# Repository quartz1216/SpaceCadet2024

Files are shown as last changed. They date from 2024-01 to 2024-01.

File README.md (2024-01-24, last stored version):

# SpaceCadet2024
## Schematic
schematic

## Parts
私が使用したパーツを記します。

## Using Assets & Lisence
- kbd  Copyright (c) 2020 foostan https://github.com/foostan/kbd
- MX_V2 Copyright (c) 2017 ai03 https://github.com/ai03-2725/MX_V2
- Type-C.pretty https://github.com/ai03-2725/Type-C.pretty

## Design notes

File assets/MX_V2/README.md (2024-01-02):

# Warning
This library is in development and has yet to be tested in production.  
Please use at your own risk.  

Cover Image 
# MX_V2
Second generation KiCad Libraries of keyboard switch footprints  

<!-- ![Footprint Image](https://raw.githubusercontent.com/ai03-2725/MX_Alps_Hybrid.pretty/master/Screenshots/Footprint.png)   -->
6 years after the creation of [the original MX_Alps_Hybrid library](https://github.com/ai03-2725/MX_Alps_Hybrid), this library has been created as a successor and replacement.

## Features
* Designed from scratch using official datasheets and accurate measurements
* Almost every switch size in existence
* Topside soldermask to prevent solder overflow and improve appearance
* Various keysizes for all occasions
* Keysizes are generated via the script generate.py from a single footprint, making the library extensible and maintainable
* (Will be) used for production PCBs and battle-tested in the real world

## Included Footprint Libraries
* **MX_Solderable.pretty** - For Cherry MX type switches.
* **MX_Hotswap.pretty** - For Cherry MX type switches via hotswap sockets.
* **Alps_Solderable.pretty** - For alps SKCM/SKCL, SKBM/SKBL, and clones with same pin structure.  
* **MX_Alps_Hybrid.pretty** - Hybrid MX/Alps compatible solderable footprints.
* **Switch_Misc.pretty** - Misc footprints such as LED footprints.
* Template.pretty - The template footprints that the script uses to generate footprints automatically. Do not use in production.

### Footprint Variants
* -ReversedStabilizers - Reversed stabilizer direction (north- vs south-facing).

### Misc Parts Variants
* -LED - LEDs that align to each switch footprint. Prefix denotes which type of switch they are applicable to.
* -Reversed - Inverts pin 1 order (left vs right square pad).
* -PolarityMarked - Marks pin 1 with a + icon to denote positive polarity (only useful if pin 1 is the higher voltage).

## Contributing
Verbal "Please create this" will usually be declined due to lack of time available for maintenance.  
Massive overhauls that completely change the structure of the library or code will be declined if made without prior discussion.  
When creating PRs, please verify the following:  
* A template footprint is created in Template.pretty if creating a new family type, with the file modified to have "Template" for all script-replaced unit/variant text.  
* Code modifications are done in a sane, clean manner.
* Footprints are made from datasheets, empirical testing, and/or reasonable expectations.
* All footprints in a switch library (i.e. not a one-off LED footprint or similar) are generated from the script and are not manually modified.

### Todo
* Script: Make ISO outlines scale by unit width/height parameters
* Add 3D models of sockets to hotswap footprints
  * Make a 3D model of a socket to begin with
* Add screenshots of 3D model, footprint
* Create useful schema symbols

## Credits
* All authors and contributors to the [original V1 switch library](https://github.com/ai03-2725/MX_Alps_Hybrid)

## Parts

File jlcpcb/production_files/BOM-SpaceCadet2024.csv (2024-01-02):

Comment | Designator | Footprint | LCSC
100n | C5,C6,C7,C8,C9 | C_0402_1005Metric | C1525
HRO-TYPE-C-31-M-12 | IO1 | HRO-TYPE-C-31-M-12 | C165948
4.7u | C3 | C_0402_1005Metric | C23733
5.1k | R1,R2,R3,R4 | R_0402_1005Metric | C25905
USBLC6-2SC6 | U2 | SOT-23-6 | C2827654
500mA | F1 | Fuse_1206_3216Metric | C2984676
1u | C1,C2,C4 | C_0402_1005Metric | C52923
XC6206PxxxMR | U3 | SOT-23-3 | C5446
STM32F072C8Tx | U1 | LQFP-48_7x7mm_P0.5mm | C80488
SW_PUSH | SW9 | MX-Hotswap-1U
SW_PUSH | SW19 | MX-Hotswap-1U
SW_PUSH | SW38 | MX-Hotswap-1U
SW_PUSH | SW14 | MX-Hotswap-1U
SW_PUSH | SW39 | MX-Hotswap-1U
SW_PUSH | SW40 | MX-Hotswap-1U
SW_PUSH | SW21 | MX-Hotswap-1U
SW_PUSH | SW56 | MX-Hotswap-1U
SW_PUSH | SW45 | MX-Hotswap-1U
SW_PUSH | SW30 | MX-Hotswap-1U
SW_PUSH | SW50 | MX-Hotswap-1U
SW_PUSH | SW33 | MX-Hotswap-1U
SW_PUSH | SW59 | MX-Hotswap-1U
SW_PUSH | SW58 | MX-Hotswap-1U
SW_PUSH | SW12 | MX-Hotswap-1U
SW_PUSH | SW32 | MX-Hotswap-1U
SW_PUSH | SW10 | MX-Hotswap-1U
SW_PUSH | SW22 | MX-Hotswap-1U
SW_PUSH | SW43 | MX-Hotswap-1U
SW_PUSH | SW8 | MX-Hotswap-1U
SW_PUSH | SW55 | MX-Hotswap-1U
SW_PUSH | SW44 | MX-Hotswap-1U
SW_PUSH | SW37 | MX-Hotswap-1U
SW_PUSH | SW1 | MX-Hotswap-1U
SW_PUSH | SW28 | MX-Hotswap-1U
SW_PUSH | SW47 | MX-Hotswap-1U
SW_PUSH | SW29 | MX-Hotswap-1U
SW_PUSH | SW31 | MX-Hotswap-1U
SW_PUSH | SW24 | MX-Hotswap-1U
SW_PUSH | SW27 | MX-Hotswap-1U
SW_PUSH | SW57 | MX-Hotswap-1U
SW_PUSH | SW13 | MX-Hotswap-1U
SW_PUSH | SW53 | MX-Hotswap-1U
SW_PUSH | SW34 | MX-Hotswap-1U
SW_PUSH | SW60 | MX-Hotswap-1U
SW_PUSH | SW17 | MX-Hotswap-1U
SW_PUSH | SW6 | MX-Hotswap-1U
SW_PUSH | SW41 | MX-Hotswap-1U
SW_PUSH | SW52 | MX-Hotswap-1U
SW_PUSH | SW25 | MX-Hotswap-1U
SW_PUSH | SW48 | MX-Hotswap-1U
SW_PUSH | SW42 | MX-Hotswap-1U
SW_PUSH | SW36 | MX-Hotswap-1U
SW_PUSH | SW7 | MX-Hotswap-1U
SW_PUSH | SW4 | MX-Hotswap-1U
SW_PUSH | SW3 | MX-Hotswap-1U
SW_PUSH | SW18 | MX-Hotswap-1U
SW_PUSH | SW11 | MX-Hotswap-1U
SW_PUSH | SW49 | MX-Hotswap-1U
SW_PUSH | SW16 | MX-Hotswap-1U
SW_PUSH | SW20 | MX-Hotswap-1U
SW_PUSH | SW46 | MX-Hotswap-1U
SW_PUSH | SW35 | MX-Hotswap-1U
SW_PUSH | SW15 | MX-Hotswap-1U
SW_PUSH | SW26 | MX-Hotswap-1U
SW_PUSH | SW2 | MX-Hotswap-1U
SW_PUSH | SW5 | MX-Hotswap-1U
SW_PUSH | SW23 | MX-Hotswap-1U
SW_PUSH | SW54 | MX-Hotswap-1U
SW_PUSH | SW51 | MX-Hotswap-1U
D_Small | D12 | D3_SMD
D_Small | D8 | D3_SMD
D_Small | D44 | D3_SMD
RST | RS1 | ResetSW
D_Small | D40 | D3_SMD
D_Small | D27 | D3_SMD
D_Small | D19 | D3_SMD
D_Small | D32 | D3_SMD
D_Small | D4 | D3_SMD
D_Small | D38 | D3_SMD
D_Small | D3 | D3_SMD
D_Small | D52 | D3_SMD
D_Small | D2 | D3_SMD
D_Small | D18 | D3_SMD
D_Small | D45 | D3_SMD
D_Small | D58 | D3_SMD
D_Small | D6 | D3_SMD
D_Small | D59 | D3_SMD
D_Small | D37 | D3_SMD
D_Small | D43 | D3_SMD
D_Small | D50 | D3_SMD
D_Small | D1 | D3_SMD
D_Small | D53 | D3_SMD
D_Small | D48 | D3_SMD
D_Small | D60 | D3_SMD
D_Small | D33 | D3_SMD
D_Small | D39 | D3_SMD
D_Small | D46 | D3_SMD
D_Small | D26 | D3_SMD
D_Small | D23 | D3_SMD
D_Small | D15 | D3_SMD
D_Small | D7 | D3_SMD
D_Small | D30 | D3_SMD
D_Small | D20 | D3_SMD
D_Small | D22 | D3_SMD
D_Small | D34 | D3_SMD
D_Small | D36 | D3_SMD
D_Small | D41 | D3_SMD
D_Small | D49 | D3_SMD
D_Small | D47 | D3_SMD
D_Small | D42 | D3_SMD
D_Small | D29 | D3_SMD
D_Small | D5 | D3_SMD
D_Small | D25 | D3_SMD
D_Small | D35 | D3_SMD
D_Small | D28 | D3_SMD
D_Small | D14 | D3_SMD
D_Small | D51 | D3_SMD
D_Small | D13 | D3_SMD
D_Small | D21 | D3_SMD
D_Small | D11 | D3_SMD
D_Small | D9 | D3_SMD
D_Small | D10 | D3_SMD
D_Small | D54 | D3_SMD
D_Small | D31 | D3_SMD
BOOT | BT1 | ResetSW
D_Small | D55 | D3_SMD
D_Small | D16 | D3_SMD
D_Small | D56 | D3_SMD
D_Small | D17 | D3_SMD
D_Small | D24 | D3_SMD
D_Small | D57 | D3_SMD

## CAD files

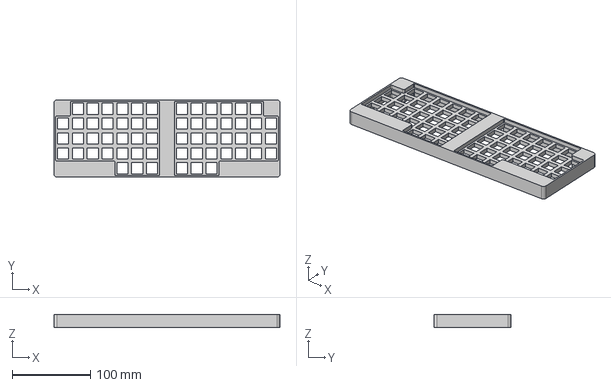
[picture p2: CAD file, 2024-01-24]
case.step
289.0 x 99.0 x 17.0 mm

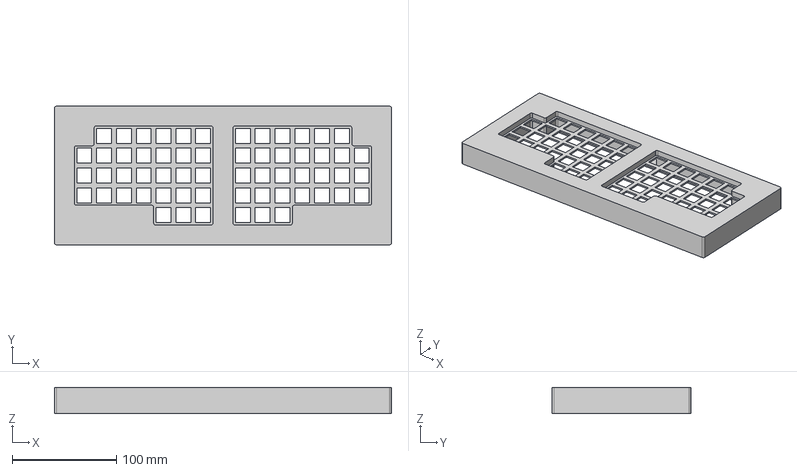
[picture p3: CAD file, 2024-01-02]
SpaceCadet2024 v8.step
323.0 x 133.0 x 25.0 mm

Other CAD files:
case.f3z

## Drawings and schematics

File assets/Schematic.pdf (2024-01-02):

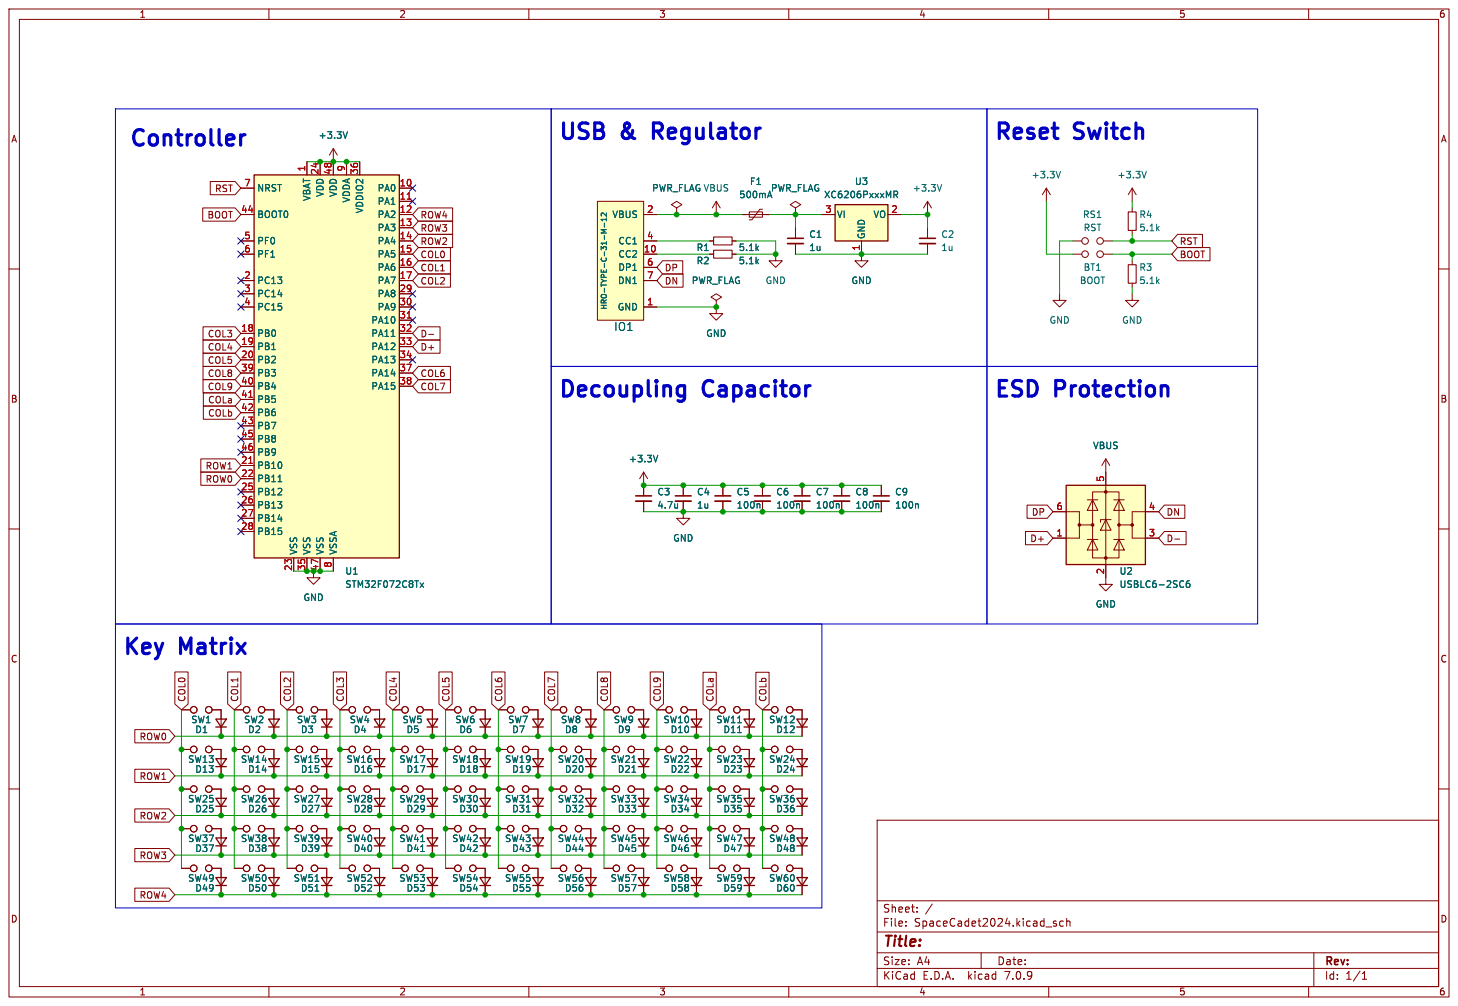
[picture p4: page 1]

1 PA0 10 PA1 11 PA2 12 PA3 13 PA4 14 PA5 15 PA6 16 PA7 17 PB0 18 PB1 19 PC13 2 PB2 20 PB10 21 PB11 22 VSS 23 VDD 24 PB12 25 PB13 26 PB14 27 PB15 28 PA8 29 PC14 3 PA9 30 PA10 31 PA11 32 PA12 33 PA13 34 VSS 35 VDDIO2 36 PA14 37 PA15 38 PB3 39 PC15 4 PB4 40 PB5 41 PB6 42 PB7 43 BOOT0 44 PB8 45 PB9 46 VSS 47 VDD 48 PF0 5 PF1 6 NRST 7 VSSA

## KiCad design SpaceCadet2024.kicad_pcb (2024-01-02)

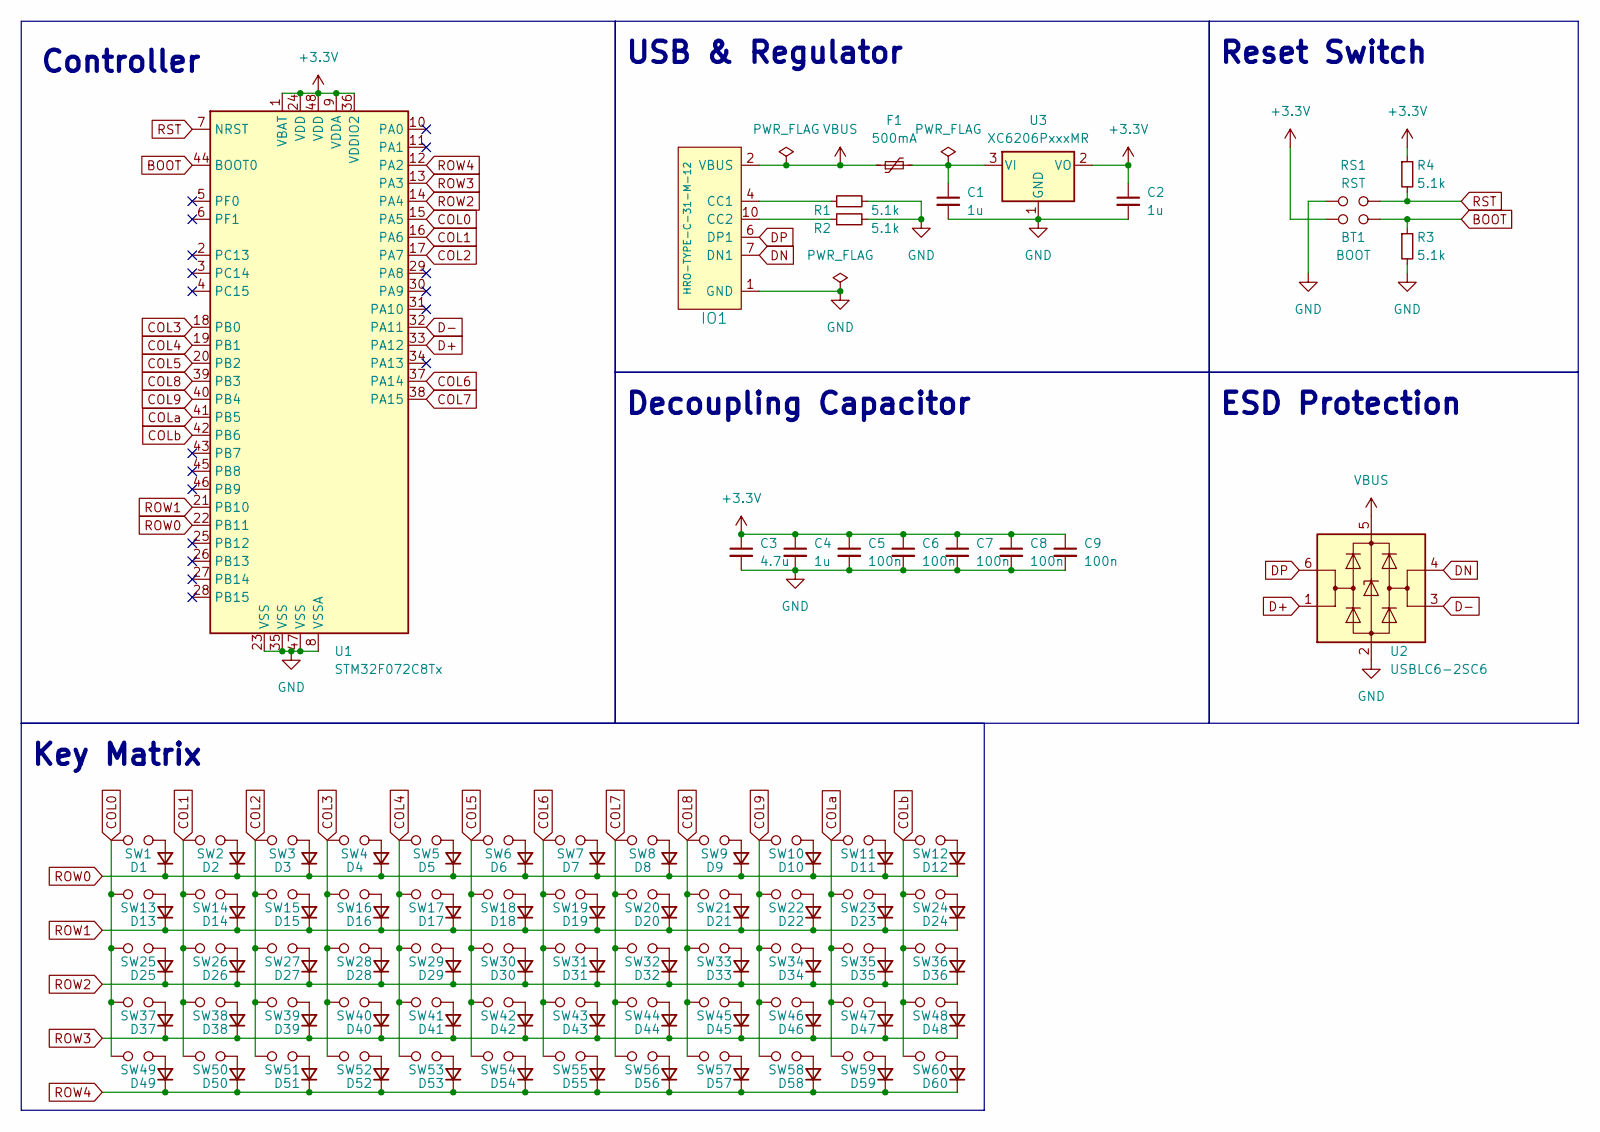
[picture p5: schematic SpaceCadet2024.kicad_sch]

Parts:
BT1: BOOT; ResetSW
C1, C2, C4: 1u; C_0402_1005Metric; LCSC C52923
C3: 4.7u; C_0402_1005Metric; LCSC C23733
C5, C6, C7, C8, C9: 100n; C_0402_1005Metric; LCSC C1525
D1, D2, D3, D4, D5, D6, D7, D8, D9, D10, D11, D12, D13, D14, D15, D16, D17, D18, D19, D20, D21, D22, D23, D24, D25, D26, D27, D28, D29, D30, D31, D32, D33, D34, D35, D36, D37, D38, D39, D40, D41, D42, D43, D44, D45, D46, D47, D48, D49, D50, D51, D52, D53, D54, D55, D56, D57, D58, D59, D60: D_Small; D3_SMD
F1: 500mA; Fuse_1206_3216Metric; LCSC C2984676
IO1: HRO-TYPE-C-31-M-12; LCSC C165948
R1, R2, R3, R4: 5.1k; R_0402_1005Metric; LCSC C25905
RS1: RST; ResetSW
SW1, SW2, SW3, SW4, SW5, SW6, SW7, SW8, SW9, SW10, SW11, SW12, SW13, SW14, SW15, SW16, SW17, SW18, SW19, SW20, SW21, SW22, SW23, SW24, SW25, SW26, SW27, SW28, SW29, SW30, SW31, SW32, SW33, SW34, SW35, SW36, SW37, SW38, SW39, SW40, SW41, SW42, SW43, SW44, SW45, SW46, SW47, SW48, SW49, SW50, SW51, SW52, SW53, SW54, SW55, SW56, SW57, SW58, SW59, SW60: SW_PUSH; MX-Hotswap-1U
U1: STM32F072C8Tx; LQFP-48_7x7mm_P0.5mm; LCSC C80488
U2: USBLC6-2SC6; SOT-23-6; LCSC C2827654
U3: XC6206PxxxMR; SOT-23-3; LCSC C5446

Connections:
+3.3V: BT1.1, C2.1, C3.1, C4.1, C5.1, C6.1, C7.1, C8.1, C9.1, R4.1, U1.1 (VBAT), U1.9 (VDDA), U1.24 (VDD), U1.36 (VDDIO2), U1.48 (VDD), U3.2 (VO)
BOOT: BT1.2, R3.1, U1.44 (BOOT0)
COL0: SW1.1, SW13.1, SW25.1, SW37.1, SW49.1, U1.15 (PA5)
COL1: SW2.1, SW14.1, SW26.1, SW38.1, SW50.1, U1.16 (PA6)
COL2: SW3.1, SW15.1, SW27.1, SW39.1, SW51.1, U1.17 (PA7)
COL3: SW4.1, SW16.1, SW28.1, SW40.1, SW52.1, U1.18 (PB0)
COL4: SW5.1, SW17.1, SW29.1, SW41.1, SW53.1, U1.19 (PB1)
COL5: SW6.1, SW18.1, SW30.1, SW42.1, SW54.1, U1.20 (PB2)
COL6: SW7.1, SW19.1, SW31.1, SW43.1, SW55.1, U1.37 (PA14)
COL7: SW8.1, SW20.1, SW32.1, SW44.1, SW56.1, U1.38 (PA15)
COL8: SW9.1, SW21.1, SW33.1, SW45.1, SW57.1, U1.39 (PB3)
COL9: SW10.1, SW22.1, SW34.1, SW46.1, SW58.1, U1.40 (PB4)
COLa: SW11.1, SW23.1, SW35.1, SW47.1, SW59.1, U1.41 (PB5)
COLb: SW12.1, SW24.1, SW36.1, SW48.1, SW60.1, U1.42 (PB6)
D+: U1.33 (PA12), U2.1 (I/O1)
D-: U1.32 (PA11), U2.3 (I/O2)
DN: IO1.5 (DN2), IO1.7 (DN1), U2.4 (I/O2)
DP: IO1.6 (DP1), IO1.8 (DP2), U2.6 (I/O1)
GND: C1.2, C2.2, C3.2, C4.2, C5.2, C6.2, C7.2, C8.2, C9.2, IO1.1 (GND), IO1.12 (GND), IO1.13 (SHIELD), R1.2, R2.2, R3.2, RS1.1, U1.8 (VSSA), U1.23 (VSS), U1.35 (VSS), U1.47 (VSS), U2.2 (GND), U3.1 (GND)
unnamed: D1.2 (A), SW1.2
unnamed: D2.2 (A), SW2.2
unnamed: D3.2 (A), SW3.2
unnamed: D4.2 (A), SW4.2
unnamed: D5.2 (A), SW5.2
unnamed: D6.2 (A), SW6.2
unnamed: D7.2 (A), SW7.2
unnamed: D8.2 (A), SW8.2
unnamed: D9.2 (A), SW9.2
unnamed: D10.2 (A), SW10.2
unnamed: D11.2 (A), SW11.2
unnamed: D12.2 (A), SW12.2
unnamed: D13.2 (A), SW13.2
unnamed: D14.2 (A), SW14.2
unnamed: D15.2 (A), SW15.2
unnamed: D16.2 (A), SW16.2
unnamed: D17.2 (A), SW17.2
unnamed: D18.2 (A), SW18.2
unnamed: D19.2 (A), SW19.2
unnamed: D20.2 (A), SW20.2
unnamed: D21.2 (A), SW21.2
unnamed: D22.2 (A), SW22.2
unnamed: D23.2 (A), SW23.2
unnamed: D24.2 (A), SW24.2
unnamed: D25.2 (A), SW25.2
unnamed: D26.2 (A), SW26.2
unnamed: D27.2 (A), SW27.2
unnamed: D28.2 (A), SW28.2
unnamed: D29.2 (A), SW29.2
unnamed: D30.2 (A), SW30.2
unnamed: D31.2 (A), SW31.2
unnamed: D32.2 (A), SW32.2
unnamed: D33.2 (A), SW33.2
unnamed: D34.2 (A), SW34.2
unnamed: D35.2 (A), SW35.2
unnamed: D36.2 (A), SW36.2
unnamed: D37.2 (A), SW37.2
unnamed: D38.2 (A), SW38.2
unnamed: D39.2 (A), SW39.2
unnamed: D40.2 (A), SW40.2
unnamed: D41.2 (A), SW41.2
unnamed: D42.2 (A), SW42.2
unnamed: D43.2 (A), SW43.2
unnamed: D44.2 (A), SW44.2
unnamed: D45.2 (A), SW45.2
unnamed: D46.2 (A), SW46.2
unnamed: D47.2 (A), SW47.2
unnamed: D48.2 (A), SW48.2
unnamed: D49.2 (A), SW49.2
unnamed: D50.2 (A), SW50.2
unnamed: D51.2 (A), SW51.2
unnamed: D52.2 (A), SW52.2
unnamed: D53.2 (A), SW53.2
unnamed: D54.2 (A), SW54.2
unnamed: D55.2 (A), SW55.2
unnamed: D56.2 (A), SW56.2
unnamed: D57.2 (A), SW57.2
unnamed: D58.2 (A), SW58.2
unnamed: D59.2 (A), SW59.2
unnamed: D60.2 (A), SW60.2
unnamed: IO1.4 (CC1), R1.1
unnamed: IO1.10 (CC2), R2.1
unnamed: C1.1, F1.2, U3.3 (VI)
ROW0: D1.1 (K), D2.1 (K), D3.1 (K), D4.1 (K), D5.1 (K), D6.1 (K), D7.1 (K), D8.1 (K), D9.1 (K), D10.1 (K), D11.1 (K), D12.1 (K), U1.22 (PB11)
ROW1: D13.1 (K), D14.1 (K), D15.1 (K), D16.1 (K), D17.1 (K), D18.1 (K), D19.1 (K), D20.1 (K), D21.1 (K), D22.1 (K), D23.1 (K), D24.1 (K), U1.21 (PB10)
ROW2: D25.1 (K), D26.1 (K), D27.1 (K), D28.1 (K), D29.1 (K), D30.1 (K), D31.1 (K), D32.1 (K), D33.1 (K), D34.1 (K), D35.1 (K), D36.1 (K), U1.14 (PA4)
ROW3: D37.1 (K), D38.1 (K), D39.1 (K), D40.1 (K), D41.1 (K), D42.1 (K), D43.1 (K), D44.1 (K), D45.1 (K), D46.1 (K), D47.1 (K), D48.1 (K), U1.13 (PA3)
ROW4: D49.1 (K), D50.1 (K), D51.1 (K), D52.1 (K), D53.1 (K), D54.1 (K), D55.1 (K), D56.1 (K), D57.1 (K), D58.1 (K), D59.1 (K), D60.1 (K), U1.12 (PA2)
RST: R4.2, RS1.2, U1.7 (NRST)
VBUS: F1.1, IO1.2 (VBUS), IO1.11 (VBUS), U2.5 (VBUS)

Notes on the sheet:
USB & Regulator
ESD Protection
Decoupling Capacitor
Reset Switch
Controller
Key Matrix

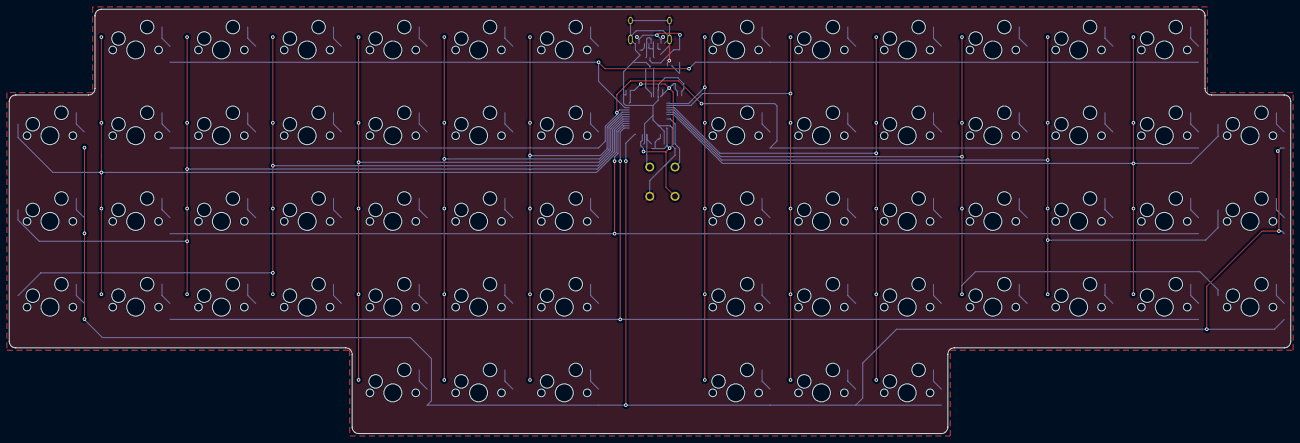
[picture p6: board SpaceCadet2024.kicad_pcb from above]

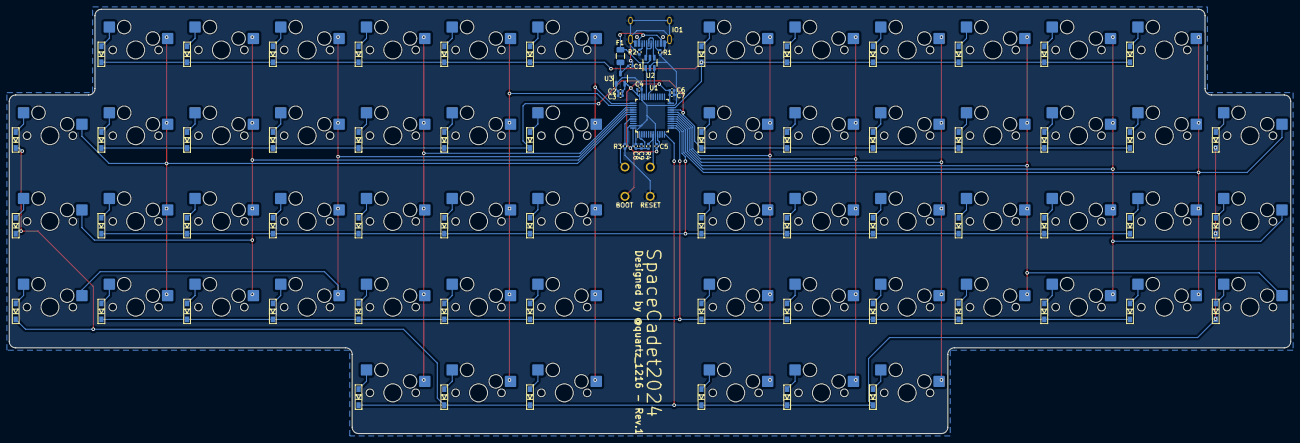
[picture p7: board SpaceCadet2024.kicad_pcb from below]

Board: 2 copper layers, 284.1 x 94.0 mm, 140 parts (80 on the bottom side), 89 nets.

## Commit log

2024-01-02 update manufacture files
    [BOM-SpaceCadet2024.csv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]
2024-01-02 upload howto images
    [SpaceCadet2024 v13bot.step, SpaceCadet2024 v13top.step]
2024-01-24 update board
    [BOM-SpaceCadet2024.csv, SpaceCadet2024 v13.f3z, SpaceCadet2024 v13.step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]
